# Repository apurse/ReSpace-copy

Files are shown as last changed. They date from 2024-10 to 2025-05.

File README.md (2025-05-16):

# RE-SPACE_GAM390

## How to start app:

### Normal start:

Open the terminal and enter: 
```
cd Re-Space-App; npm install; npx expo start -c
```

### Direct connection:
If normal start doesn't work.
Open the terminal and enter: 
```
cd Re-Space-App; npm install; npx expo start --tunnel -c
```

### Fix dependencies after update:
```
npm config set legacy-peer-deps true
```

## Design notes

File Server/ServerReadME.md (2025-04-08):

## Setup:

### Server setup: hub_communication.py

cd Server; pip install socket asyncio websockets json serial; python hub_communication.py

### Simulating a robot: robot-testing.py

cd Server; cd testing; python robot-testing.py

### wsServer.py

pip install socket asyncio websockets json serial; python wsServer.py

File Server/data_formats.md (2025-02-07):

App -> Hub:\
Control movements\
	`{type: "control", target: "<UUID>", direction: "<text_direction>"}`\
Current furniture layout (manually set)\
	`{type: "current_layout", locations: "{{id: <int>, x: <int>, y: <int>}, {id: <int>, x: <int>, y: <int>}}"}`\
Desired Layout information\
	Furniture ID's with x/y coords\
	`{type: "desired_layout", locations: "{{id: <int>, x: <int>, y: <int>}, {id: <int>, x: <int>, y: <int>}}"}`\
Status control\
	Turn robots on/off\
	`{type: "power", target: "<UUID>", data: "<on/off>"}`

*(Possible: Send furniture types/sizes to be stored on hub)*

Hub -> App:\
Real current layout configuration\
	`{type: "current_layout", locations: "{{id: <int>, x: <int>, y: <int>}, {id: <int>, x: <int>, y: <int>}}"}`\
Robot Status\
	`{type: "status", robot_id: <Websocket UUID>, battery: <int>, location: {x: <int>, y: <int>}, current_activity: "<task_id>"}`\

Robot -> Hub:\
	Robot status\
    `{type: status, battery: <int>, location: {x: <int>, y: <int>}, current_activity: "<task_id>"}`\
	Current location of a furniture item\
		*(Either from just being dropped off, or scanned with ArUco marker)*\
		`{type: "furniture_location", id: <int>, location: {x: <int>, y: <int>}}`

Hub -> Robot:\
	Go-to x/y\
`{type: "move", location: {x: <int>, y: <int>}`\
	Send move task\
`{"type": "move_task", "location_from": {"x": <fromX>, "y": <fromY>}, "location_to": {"x": <toX>, "y": <toY>}}`

Hub -> Swarm script:\
	Current robot ID's / Status'\
	Desired Configuration layout\
	Current furniture positions

Swarm script -> Hub:\
	Send move task\

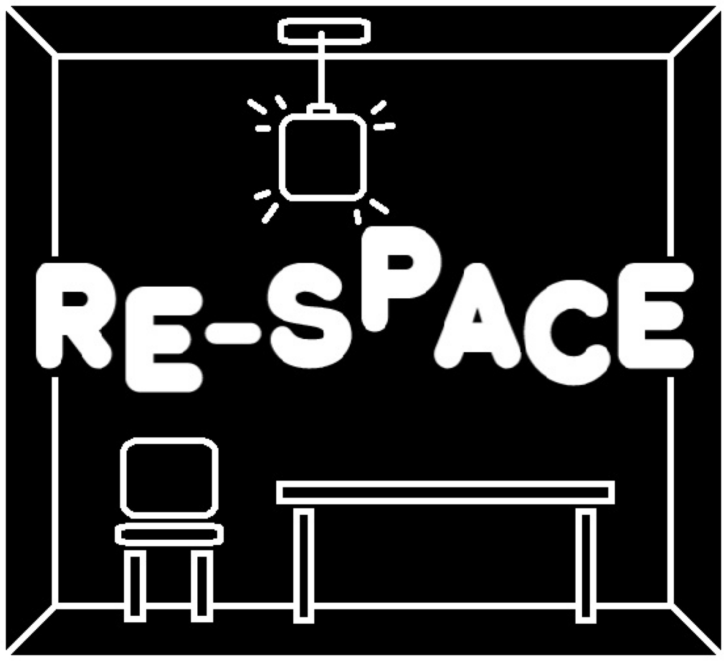
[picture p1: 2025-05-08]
Re-Space-App/assets/images/inverted.png

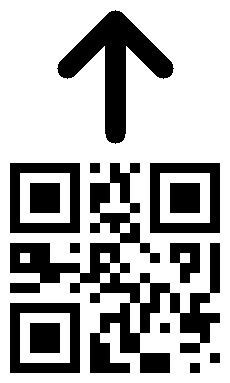
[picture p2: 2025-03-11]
Server/combined.png

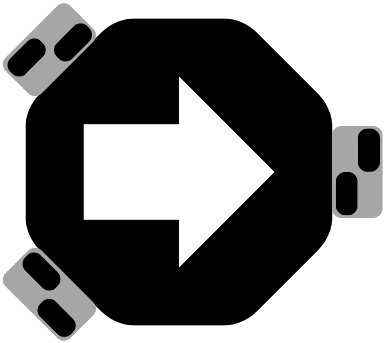
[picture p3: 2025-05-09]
Server/robot.png

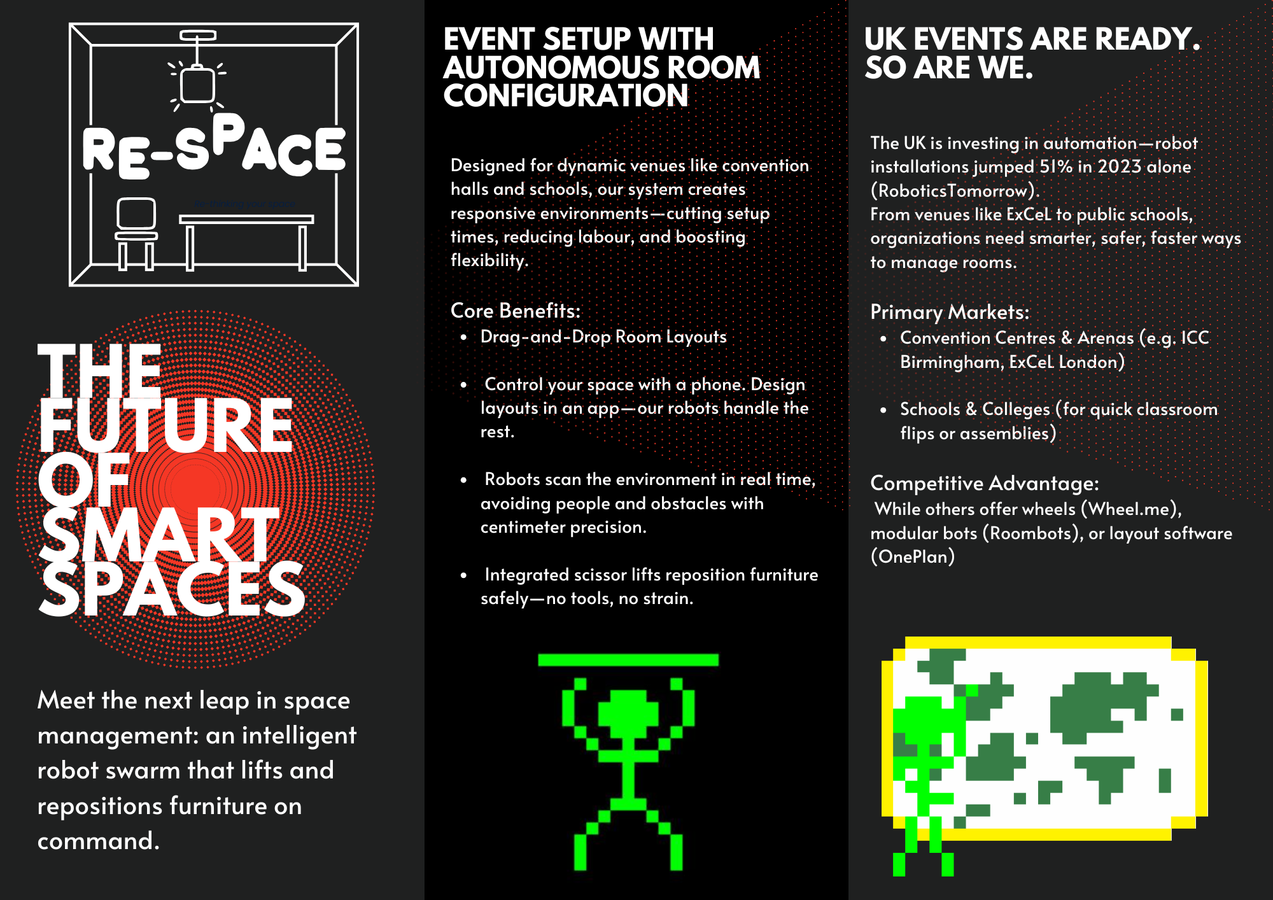
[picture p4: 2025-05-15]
Documentation/BrochurePG1.png

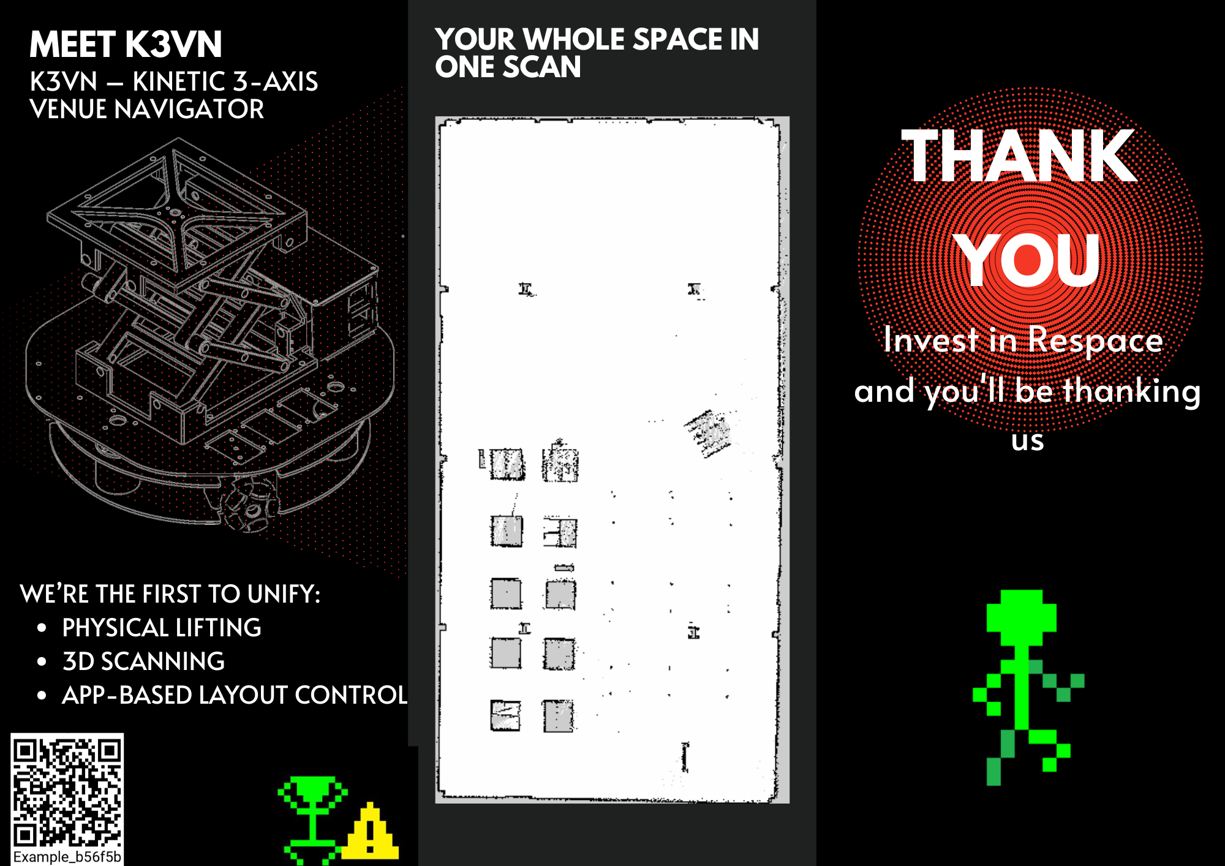
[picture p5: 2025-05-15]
Documentation/BrochurePG2.png

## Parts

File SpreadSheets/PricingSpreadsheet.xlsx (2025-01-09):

Component | price | amount | Cost
Pi4 | £55 | 2 | 110
Pi Pico | £3.90 | 1 | 3.9
Stepper motor | £9.5 | 1 | 10
stepper motor driver | £1.50 | 1 | 1.5
Filament(1 reel) | £20 | 500 grams | 20
Motors | £5 | 3 | 15
Omni Wheels | £5 | 3 | 15
Acrylic600mmx300mm | £10 | 1 | 10
PS3 eyetoy | £5 | 1 | 5
coupling | £2 | 3 | 6
Custom PCB | £30 | 1 | 30
LiPo battery | £32 | 1 | 32
 |  |  | 258.4

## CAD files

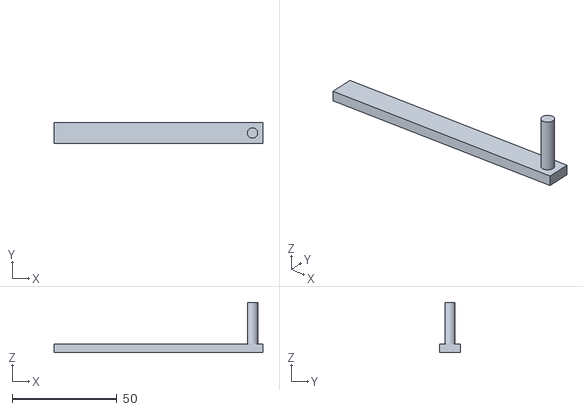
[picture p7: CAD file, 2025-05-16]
CAD/Future Developments/Fork Lift Prototyping/slider legs in face cam v1.stl
100.0 x 10.0 x 24.0

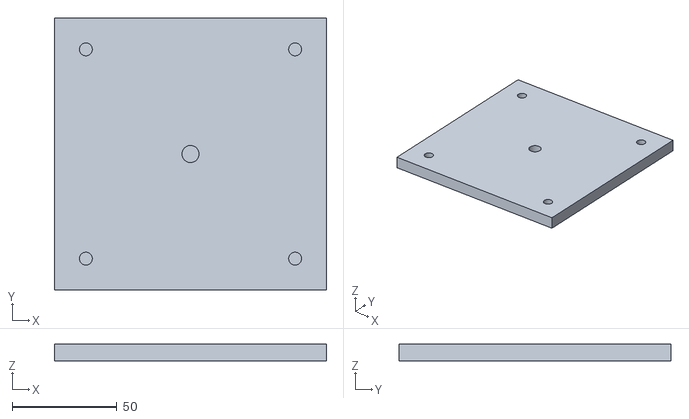
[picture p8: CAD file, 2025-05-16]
CAD/Future Developments/Fork Lift Prototyping/top plate mk2 v1.stl
130.0 x 130.0 x 8.00

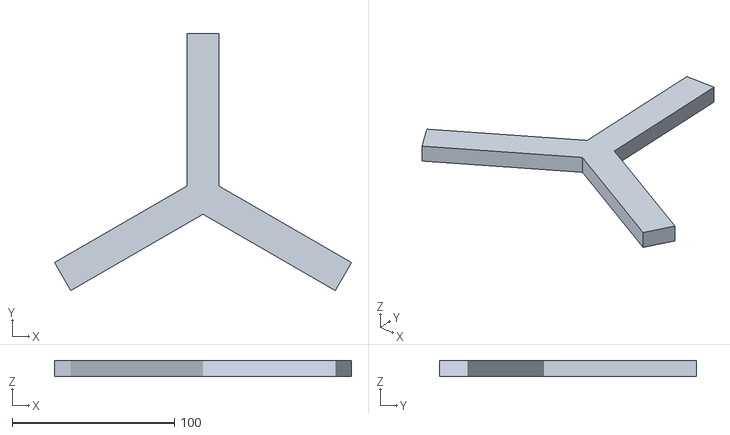
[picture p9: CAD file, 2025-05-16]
CAD/Future Developments/Fork Lift Prototyping/bottom of face cam v1.stl
183.2 x 158.7 x 10.0

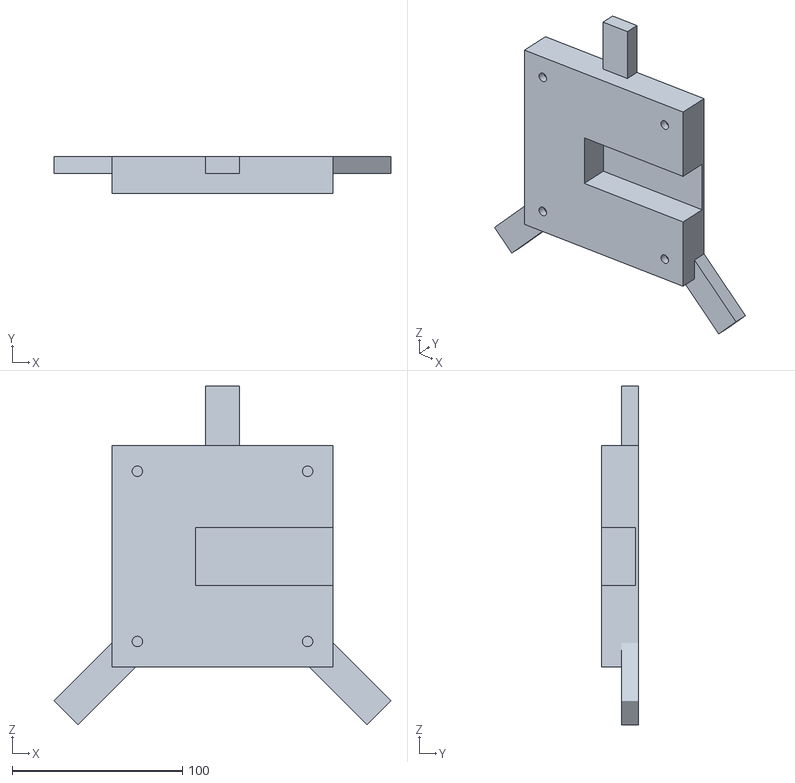
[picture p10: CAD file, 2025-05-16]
CAD/Future Developments/Fork Lift Prototyping/base mk2 v2.stl
198.0 x 22.0 x 199.0

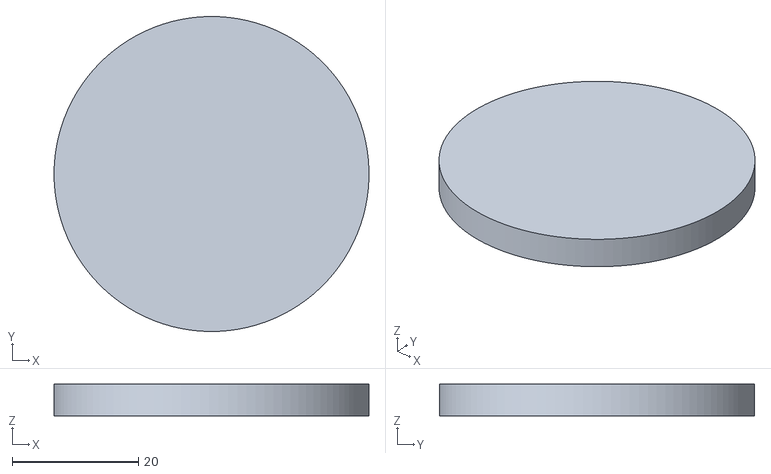
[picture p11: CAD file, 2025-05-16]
CAD/Future Developments/Fork Lift Prototyping/face of face cam v1.stl
50.0 x 50.0 x 5.00

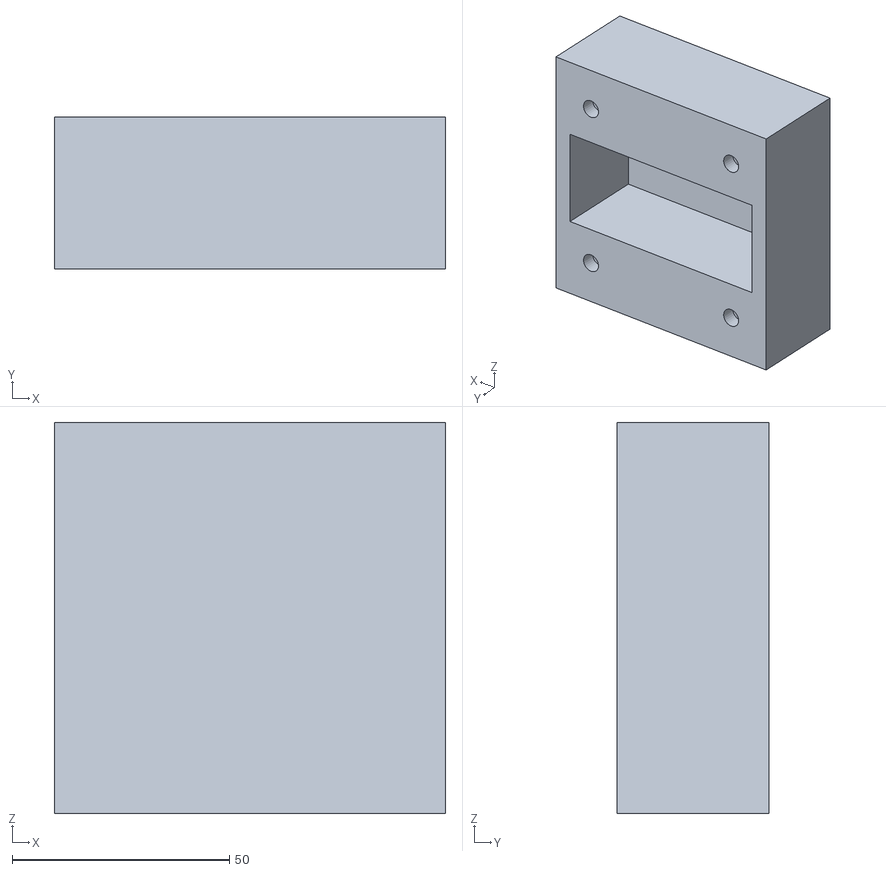
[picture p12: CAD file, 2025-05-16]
CAD/Future Developments/Fork Lift Prototyping/base v4.stl
90.0 x 35.0 x 90.0

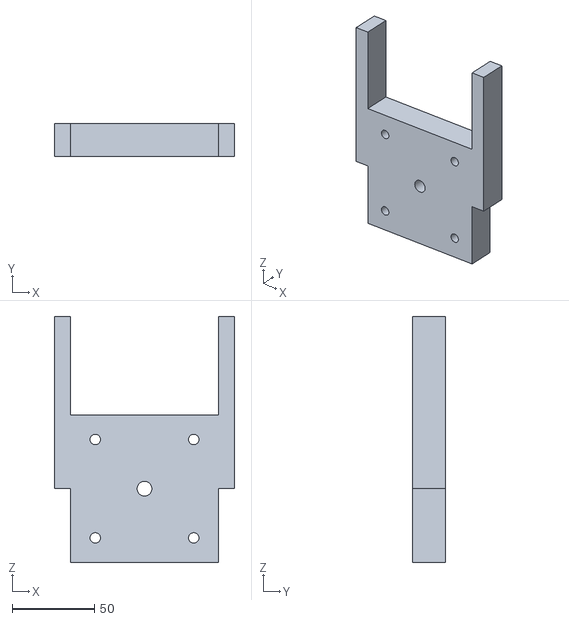
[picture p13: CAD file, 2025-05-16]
CAD/Future Developments/Fork Lift Prototyping/lifting part v3.stl
110.0 x 20.0 x 150.0

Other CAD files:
CAD/Base/Alternate Motor Mount v1.f3d
CAD/Base/Bottom Plate v9.f3d
CAD/Base/Full Assembly v51.f3z
CAD/Base/Lower Post v7.f3d
CAD/Base/Middle Plate v11.f3d
CAD/Base/Middle Post v3.f3d
CAD/Base/Top Plate v26.f3z
CAD/Base/holder v2.f3d
CAD/Dock/Assembly/FullDock.f3z
CAD/Dock/componets/LeftSlot v6.f3d
CAD/Dock/componets/MultiSideSlot v5.f3d
CAD/Dock/componets/RightSlot v4.f3d
CAD/Dock/componets/TOPpanel v1.f3d
CAD/Dock/componets/side panel v6.f3d
CAD/Peripherals/LED bumper v7.f3d
CAD/Scissor Lift/Scissor Assembly v22.f3z
CAD/Scissor Lift/new base plate v11.f3z
CAD/Scissor Lift/new inner arm v1.f3d
CAD/Scissor Lift/new outer arm v4.f3d
CAD/Scissor Lift/new top of lift v2.f3z
CAD/Scissor Lift/slider v24.f3z
CAD/Scissor Lift/small slider v1.f3d

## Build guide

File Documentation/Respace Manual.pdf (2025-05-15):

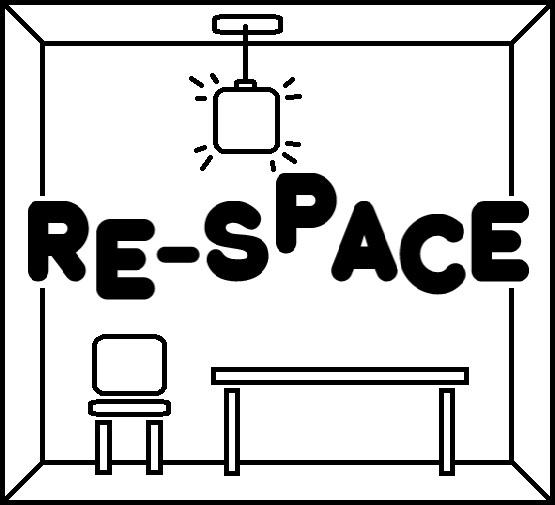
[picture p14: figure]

# ReSpace Manual

# Operating a K3VN Unit with the Proprietary App

K3VN – Kinetic 3-Axis Venue Navigator

## Robot Setup Guide

Once your robot has been delivered, there are two main steps you need to complete before using it:

1. Set up the Hub
- Choose an appropriate space for the Hub.
- Plug it into a mains power outlet.
2. Power on the Robot
- Locate the E-Stop button on the robot.
- Twist the button to turn the robot on.
- Push the button to turn the robot off.

## Configuring the App

Logging In

Once you've installed the app, you’ll be prompted to log in.

- Enter your username and password.
- If this is your first time, tap Create Account.

- If you already have an account, tap Log In.

Room Scanning

1. Tap the Rooms tab at the bottom of the screen.

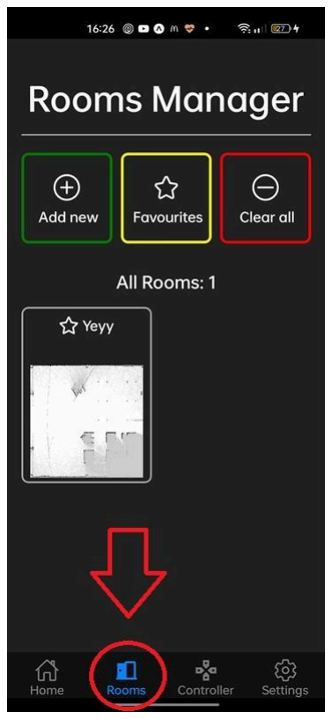
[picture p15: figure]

2. Tap Add New Room.
3. Enter a name for the room and tap Create. (You will be taken to the Room Details screen.)
4. Tap the Scanning option on the details page.

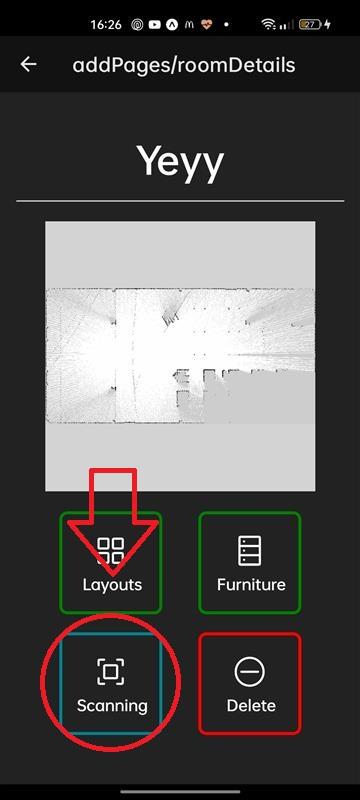
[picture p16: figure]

5. Tap the dropdown and select the desired robot.

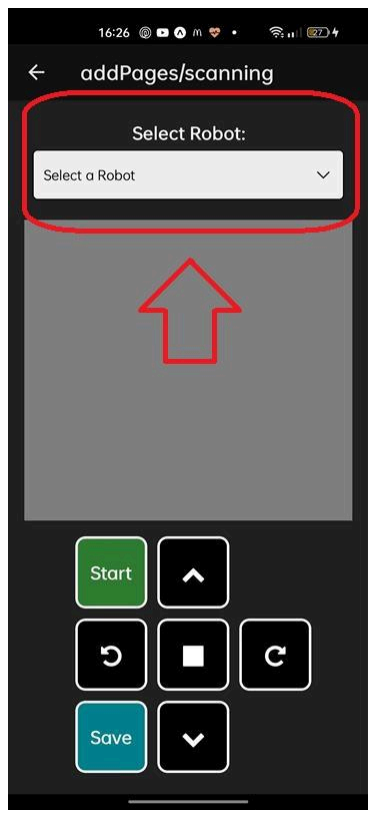
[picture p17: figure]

6. Tap Start.
- A live feed from the robot will appear.
- Use the four arrow keys (cardinal directions) to manually control the robot.

7. Move the robot around the room until you are satisfied with the scan.
8. Once all sides of the room are scanned, tap Save.

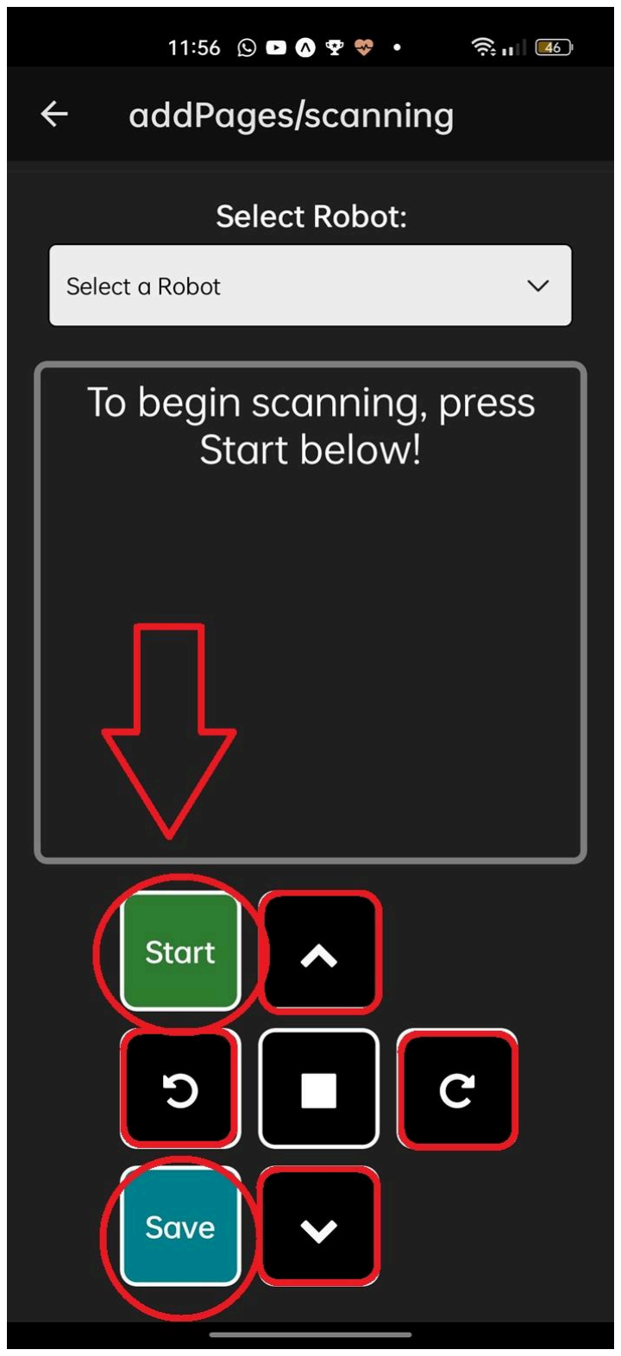
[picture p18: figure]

Adding Furniture

1. Swipe back once you’ve saved the scan.
2. Tap the Add Furniture button.
3. Enter the furniture’s dimensions as prompted.
4. Tap Save Furniture.

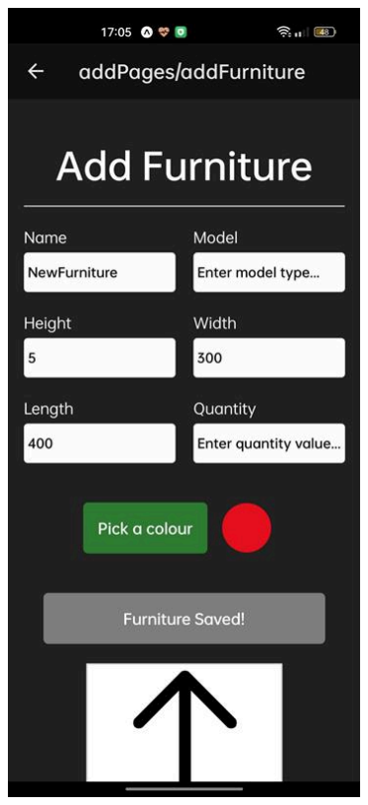
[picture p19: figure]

5. A QR code will appear—tap the Download button to save it to your camera roll.
6. Print the QR code and stick it to the underside of the furniture so it’s clearly visible (preferably in a large size).

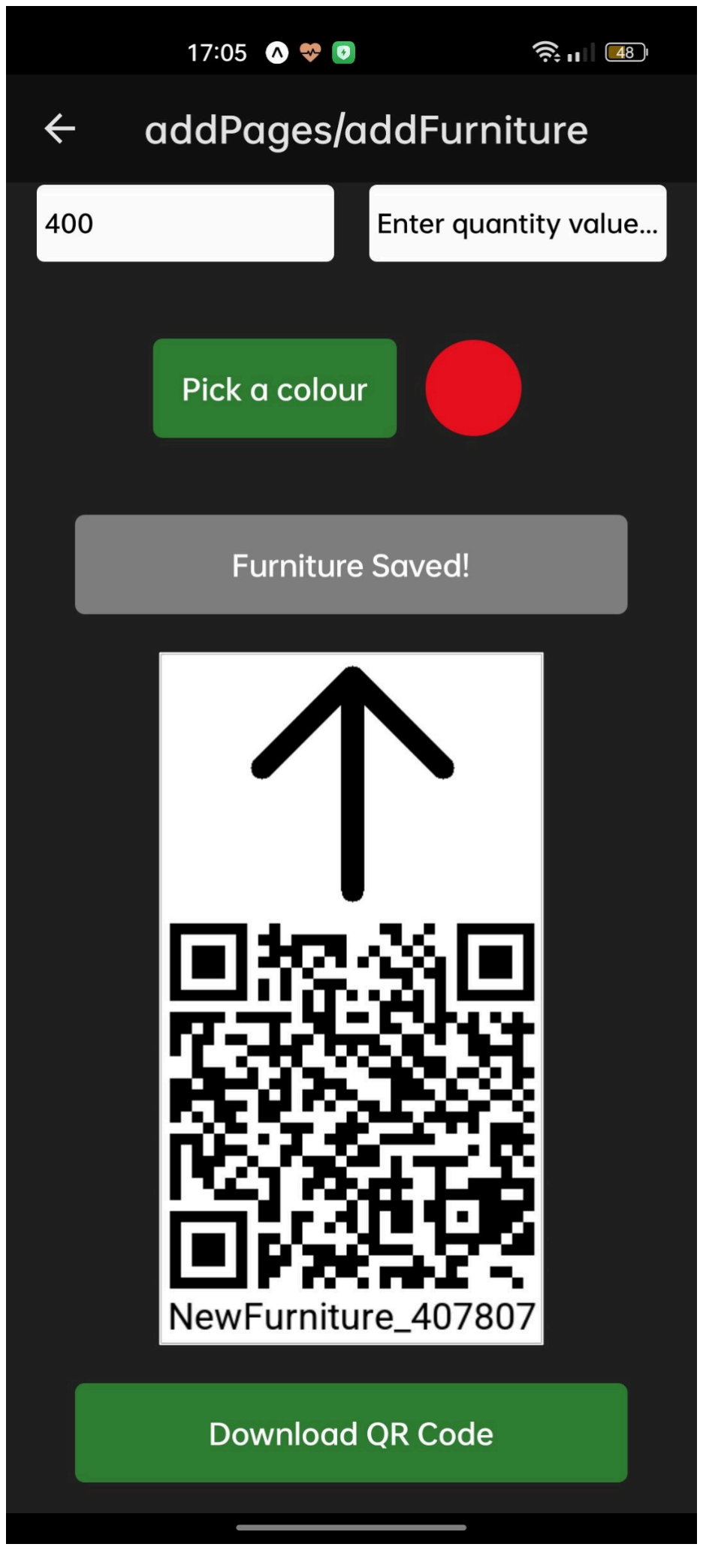
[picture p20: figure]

Adding New Layouts

1. Once a room scan and furniture are saved, go to the Room Details page.
- The most recent scan will appear.
2. Tap the Layouts tab at the bottom of the Room Details page.

3. Layout manager -> add new layout
4. Add a title for the layout.

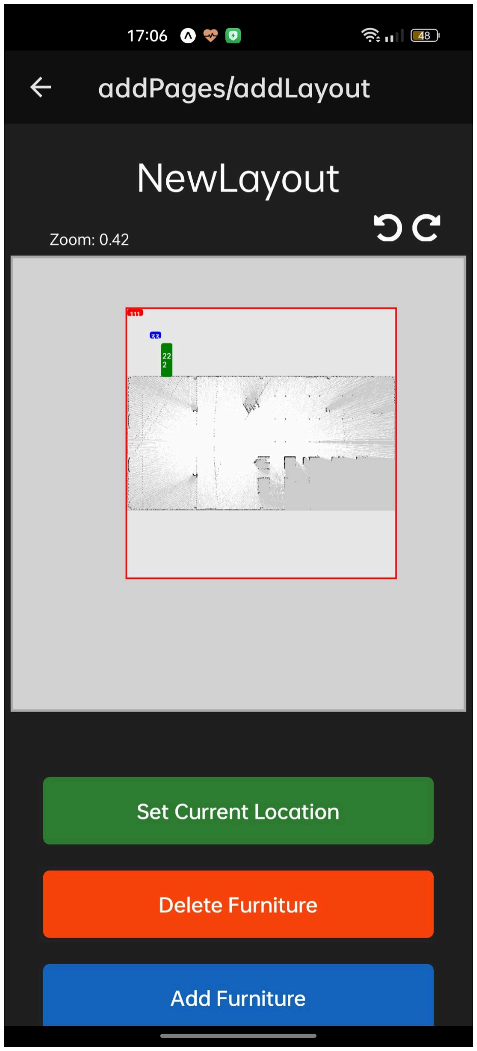
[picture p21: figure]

5. Tap the Add Furniture button.
6. Select the desired piece of furniture.
7. Drag the furniture to its current location.
8. Once you’ve placed all the furniture you want:
- Tap Set Current Location.
9. You’ll now be prompted to drag the furniture again—this time to the desired location.
10. Drag the furniture.
11. Tap Save Layout.

## System Running Page

- After saving the layout, tap Ready to Go.

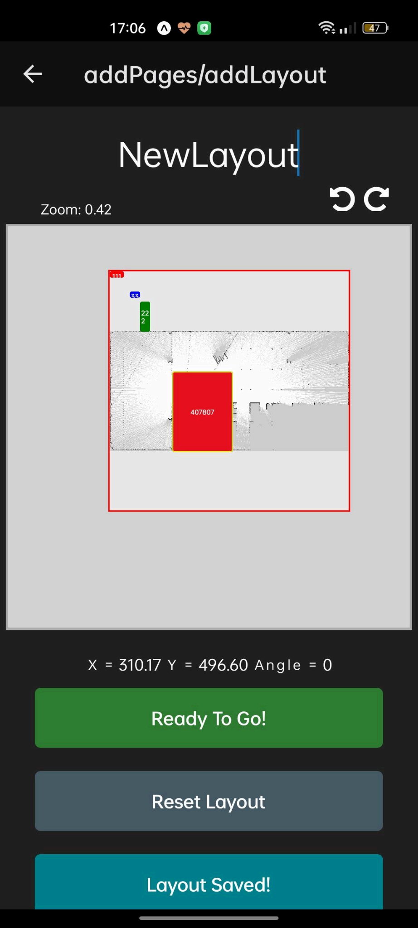
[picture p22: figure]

- The robot’s current location will load, along with a progress bar.
- The picked up furniture will update with the robots current position.
- If anything unusual happens, press the Emergency Stop button.
- Once the progress bar is full, the robot will have completed the move task.

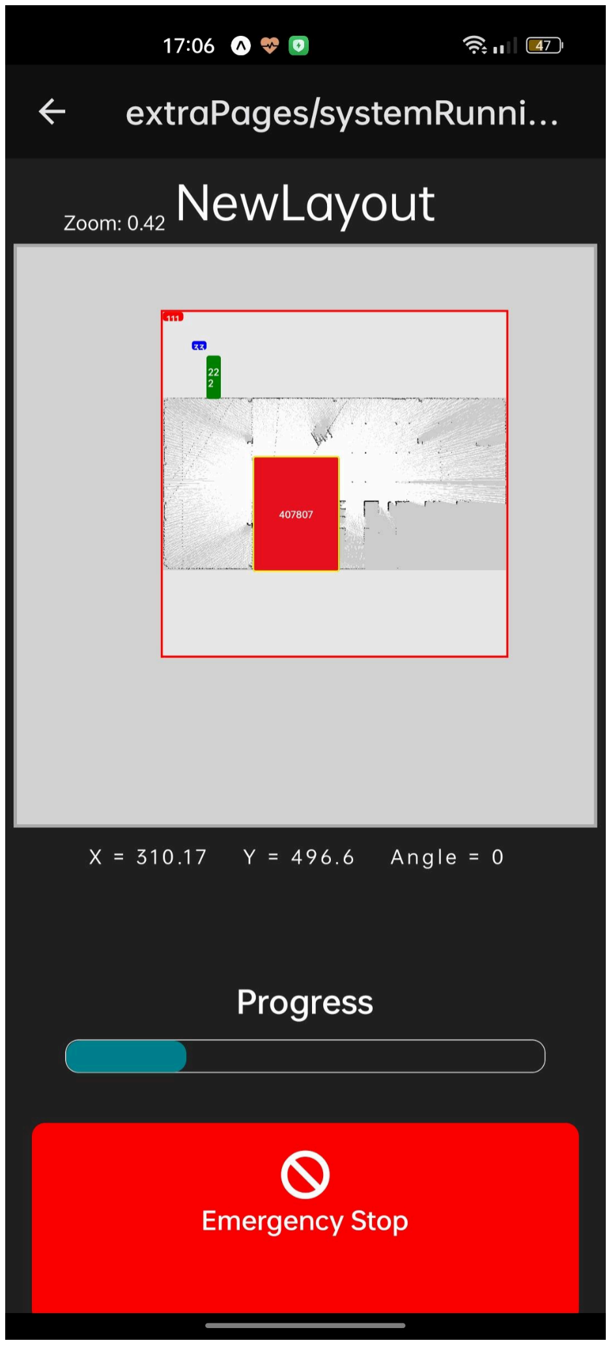
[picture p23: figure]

- Return to the home screen to add more rooms, furniture, or layouts.

## Account Settings

1. Go to the Settings tab at the bottom of the screen.
2. Tap Account Settings.
3. Re-enter your credentials as desired.

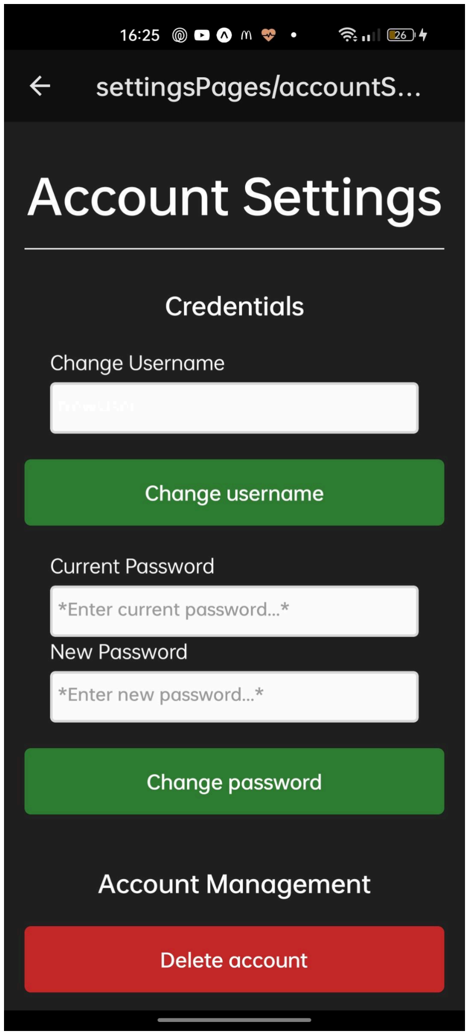
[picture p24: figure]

## General Settings

- In Settings, you can enable Dark Mode.
- You can also test the connection to ensure your robots are properly connected.

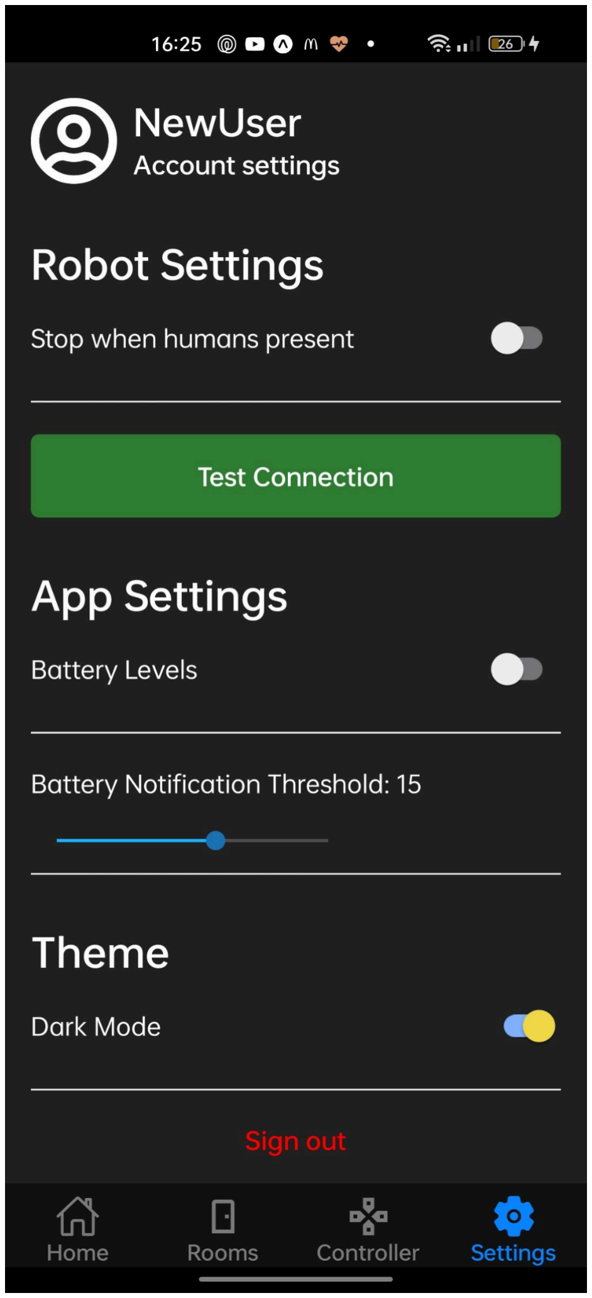
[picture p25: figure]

## Main Screen

- View the robot’s current battery life.
- See a list of connected robots.

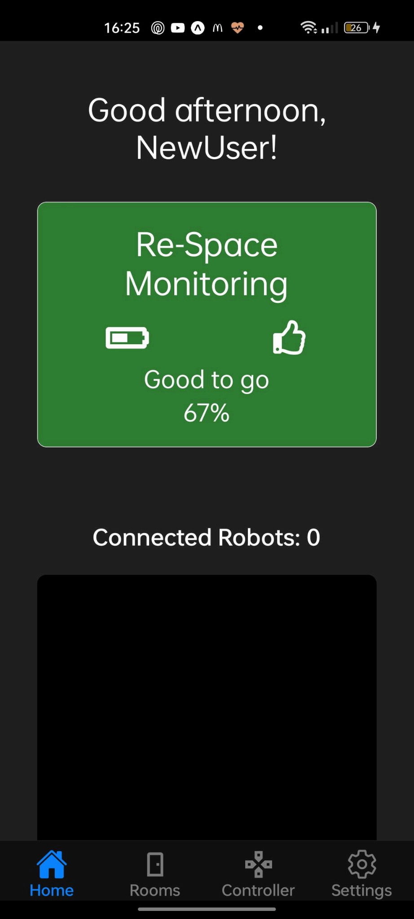
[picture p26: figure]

## Manual Control

1. Tap the Controller tab.
2. Use the arrow keys to manually control the robot.

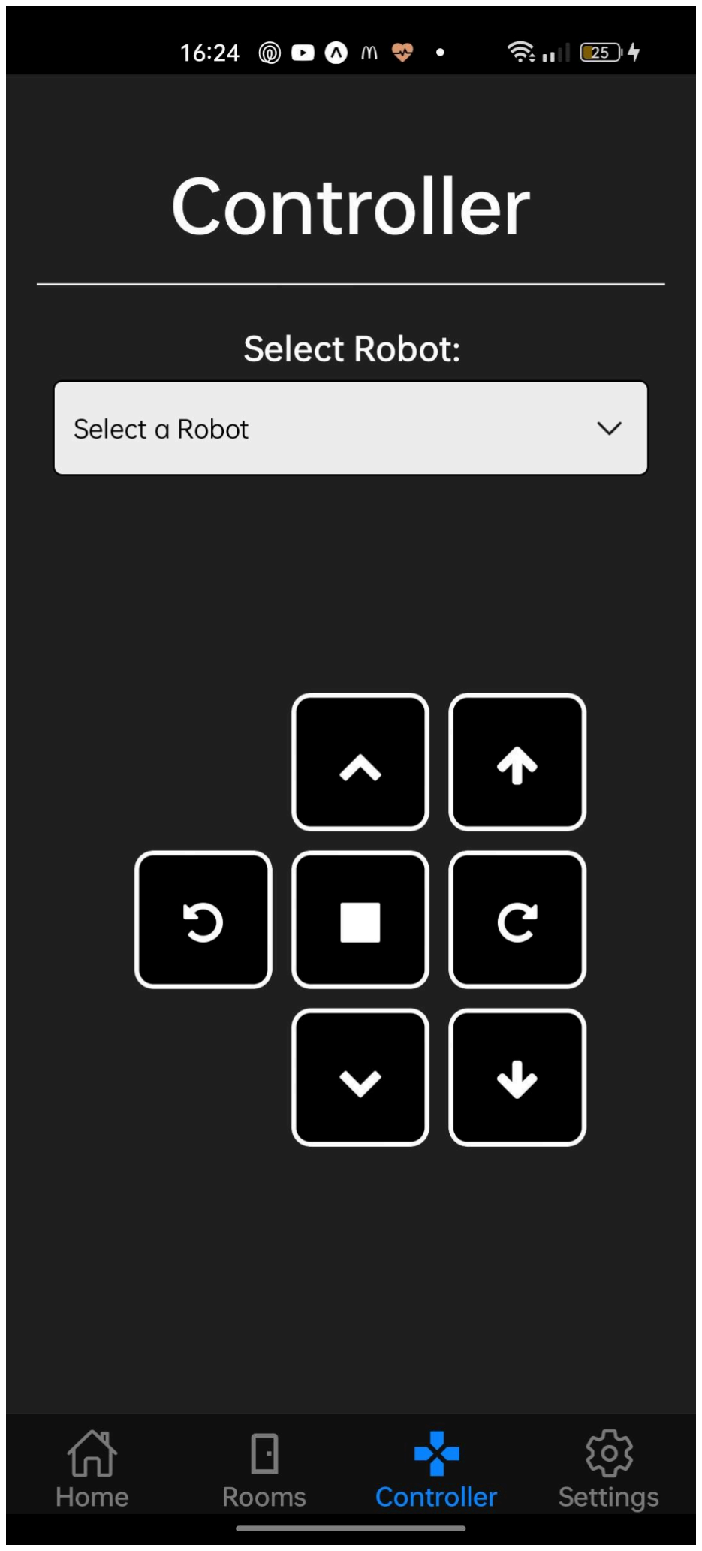
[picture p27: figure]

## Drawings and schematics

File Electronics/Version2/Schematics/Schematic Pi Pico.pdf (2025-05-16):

## ENDSTOP MICROSWITCH CONNECTORS

## BATTERY PROBE

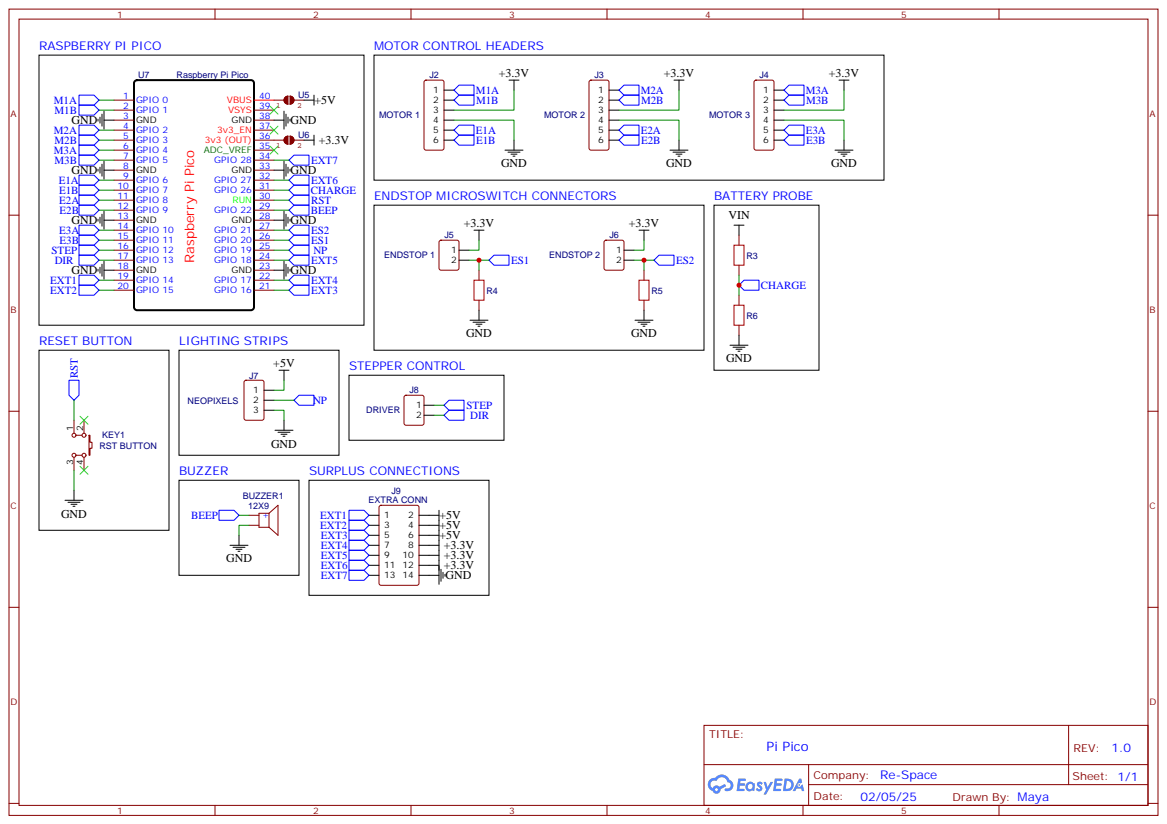
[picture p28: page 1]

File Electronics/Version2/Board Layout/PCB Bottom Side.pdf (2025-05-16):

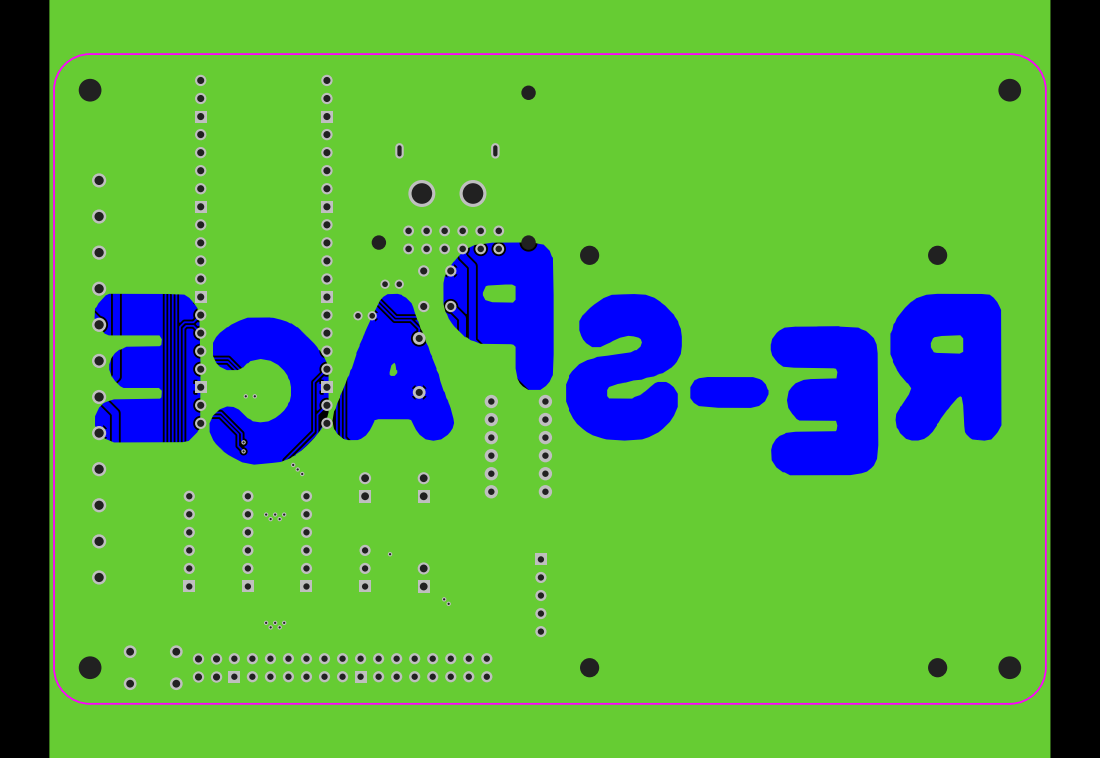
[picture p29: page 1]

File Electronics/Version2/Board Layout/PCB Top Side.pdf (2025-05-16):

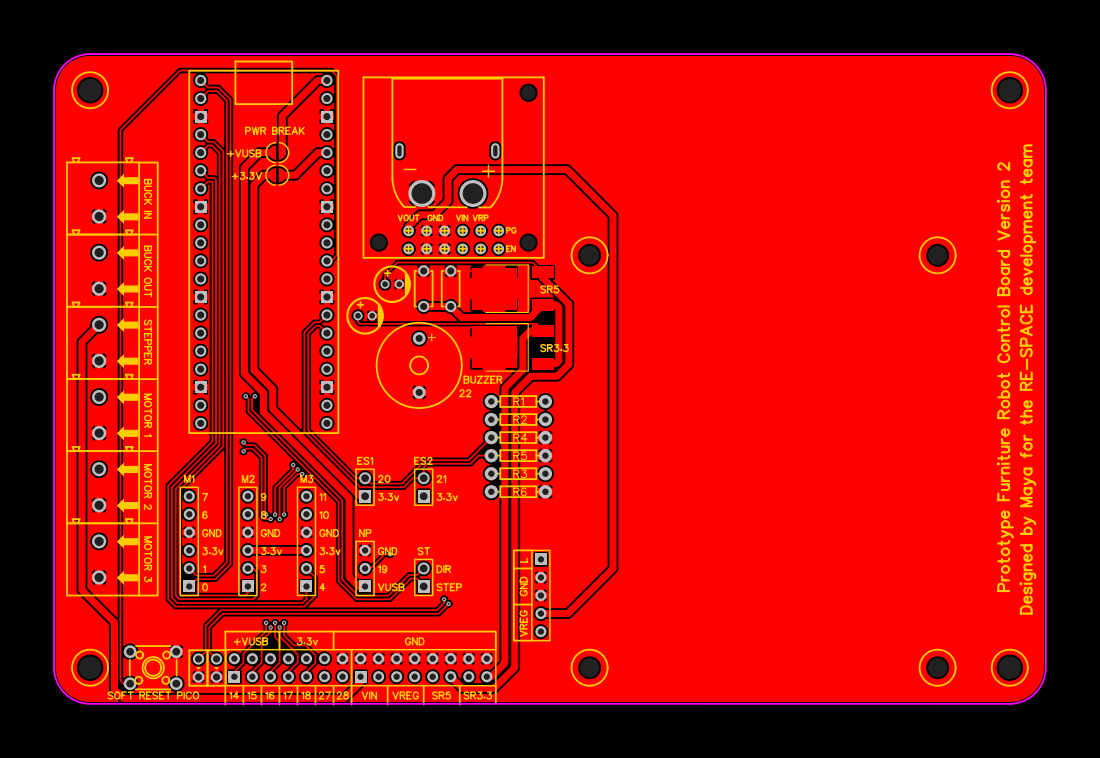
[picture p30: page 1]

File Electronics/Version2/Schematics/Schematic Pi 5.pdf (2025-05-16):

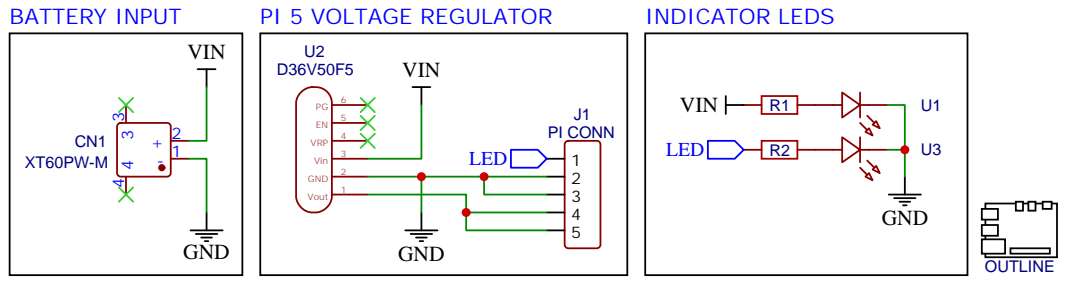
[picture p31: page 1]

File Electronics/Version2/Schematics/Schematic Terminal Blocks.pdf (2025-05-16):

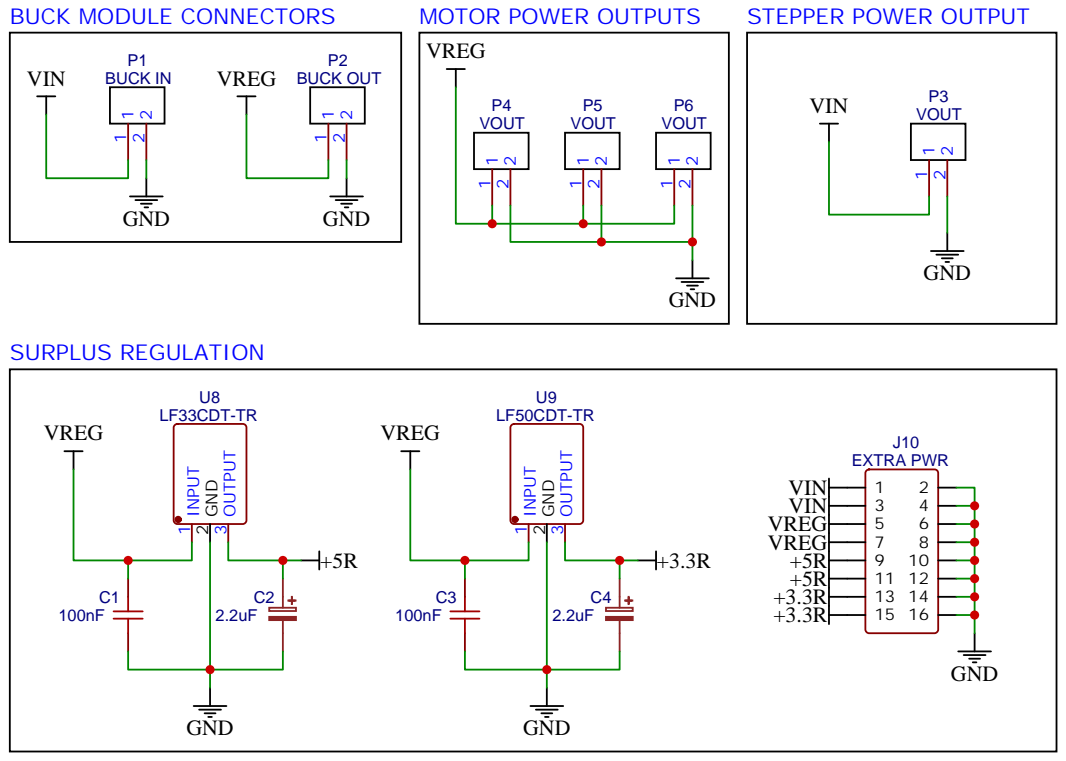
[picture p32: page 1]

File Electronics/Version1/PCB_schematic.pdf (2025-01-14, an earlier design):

## GND

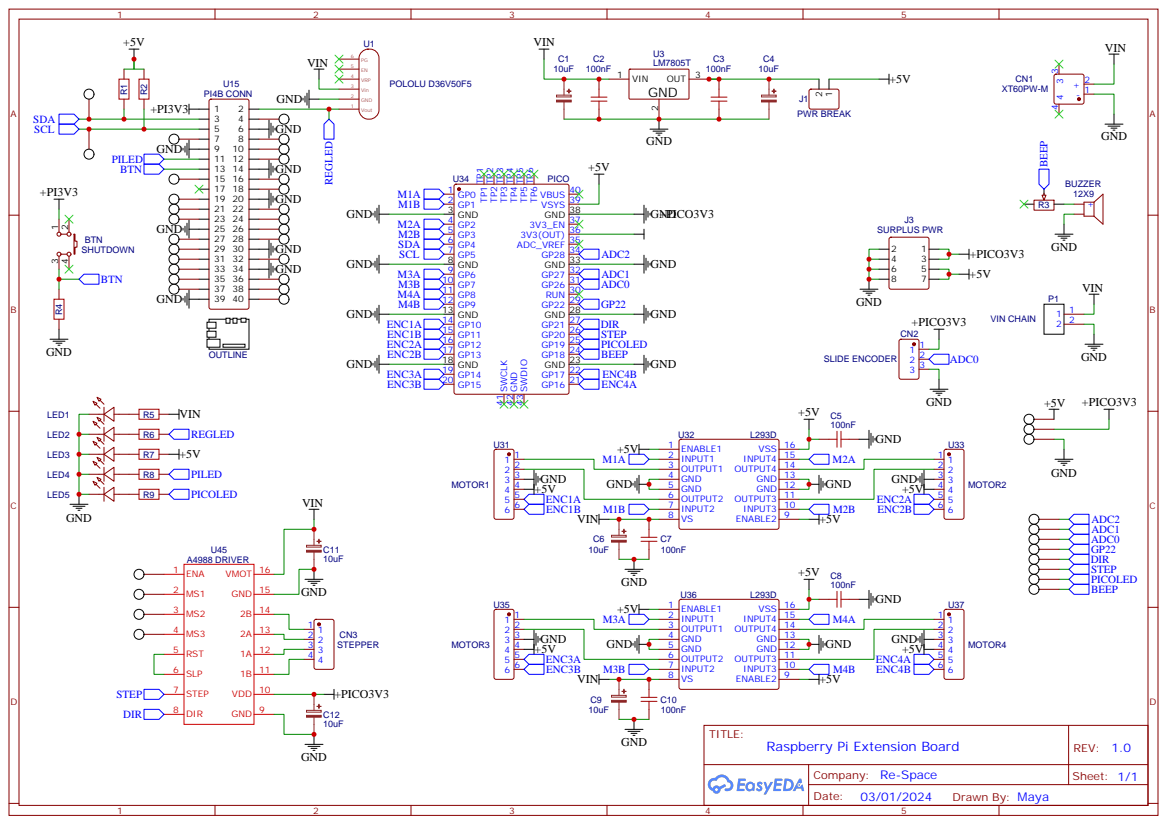
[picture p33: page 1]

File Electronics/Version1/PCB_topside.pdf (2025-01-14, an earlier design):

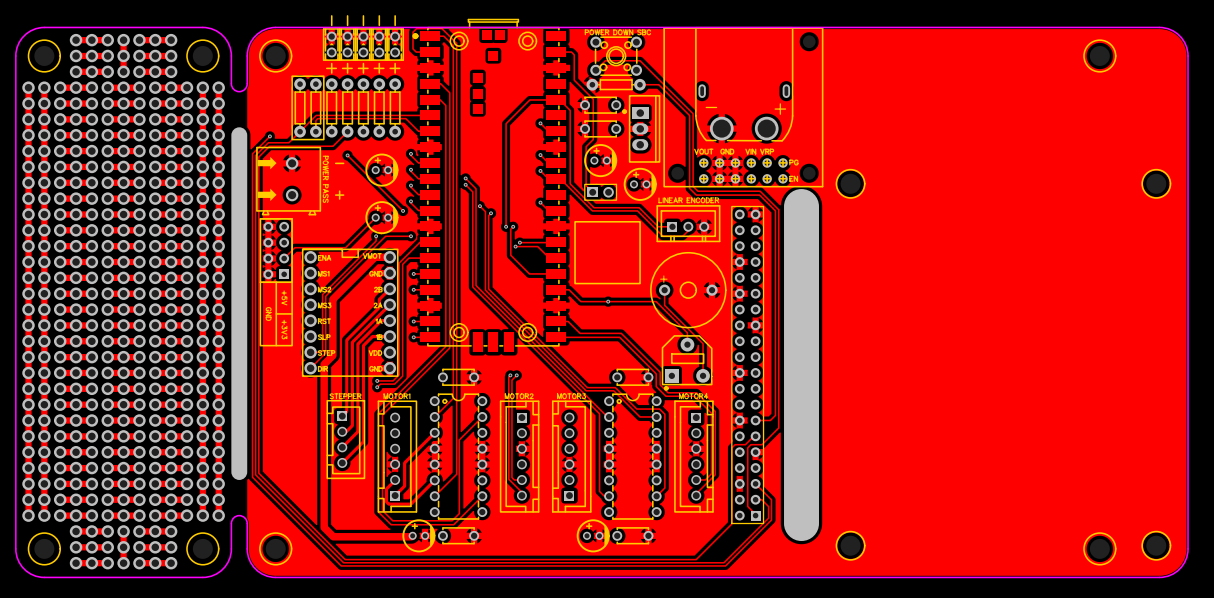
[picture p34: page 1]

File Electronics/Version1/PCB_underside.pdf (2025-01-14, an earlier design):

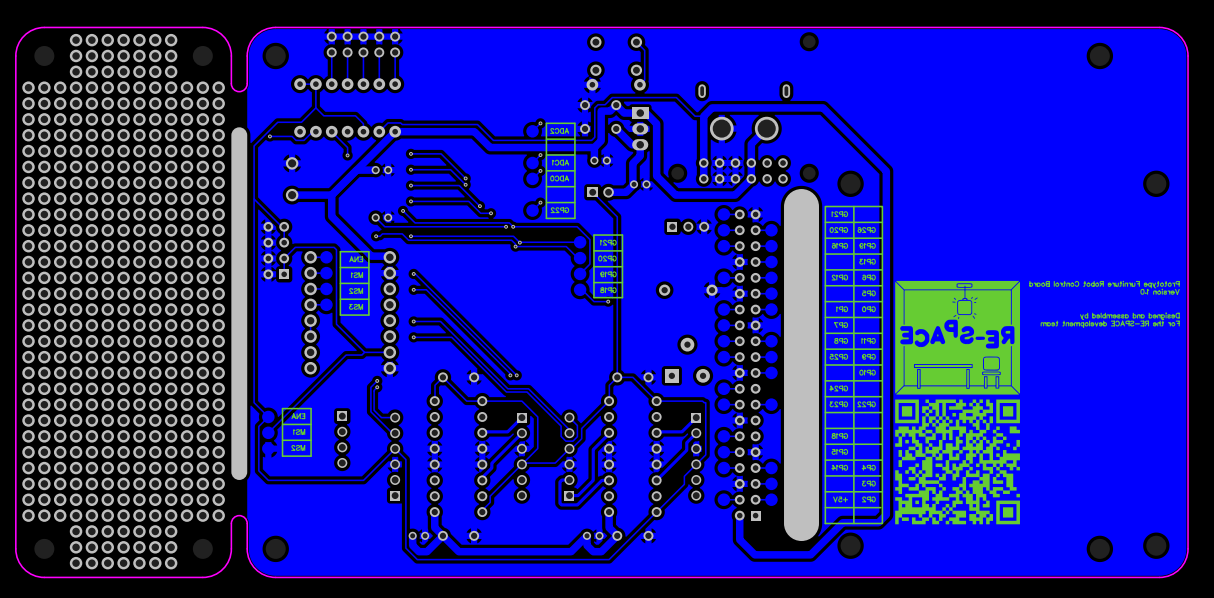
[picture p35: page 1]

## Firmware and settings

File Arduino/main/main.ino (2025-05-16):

#include "pio_encoder.h"
#include "pico/multicore.h"
#include "hardware/timer.h"
#include <AccelStepper.h>
#include <FastLED.h>

#define NUMPIXELS_PER_STRIP 28
#define NUM_STRIPS 3

#define LED_PIN_1 14
#define LED_PIN_2 15
#define LED_PIN_3 16

CRGB strip1[NUMPIXELS_PER_STRIP];
CRGB strip2[NUMPIXELS_PER_STRIP];
CRGB strip3[NUMPIXELS_PER_STRIP];

#define stepPin 12
#define dirPin 13
#define limitSwitchPin 21
#define motorInterfaceType 1

AccelStepper stepper(motorInterfaceType, stepPin, dirPin);

int switchState;
int ms = 16;
const float r = 0.029;  // Wheel radius (m)
const float circ = 3.14 * 2 * r;  // Wheel circum (m)
const float d = 0.155;   // Distance from wheel center to robot center (m)
const float dt = 0.1;  // Time step (s)
String transmission;

// Initial position of robot
float x = 0.0, y = 0.0, theta = 0.0, vx = 0.0, vy = 0.0, omega = 0.0;

// Initial HZ of motors
float HZ1 = 0.0, HZ2 = 0.0, HZ3 = 0.0;

// Motor class with encoder
class Motor {
  private:
    int motorPin1, motorPin2;
    PioEncoder encoder;
    int previousEncoder;
    float Kp, Ki, Kd;
    float previousError, integral;
    float targetSpeed, currentSpeed;
    float previousTime;
    float ticks_per_rev = 2480;

  public:
    Motor(int m1, int m2, int e1, float kp, float ki, float kd)
      : motorPin1(m1), motorPin2(m2), encoder(e1), Kp(kp), Ki(ki), Kd(kd), previousError(0), integral(0), targetSpeed(0) {}

    void begin() {
      pinMode(motorPin1, OUTPUT);
      pinMode(motorPin2, OUTPUT);
      encoder.begin();
      previousTime = millis();
      currentSpeed = 0.0;
      previousEncoder = 0;
    }

    void setTargetSpeed(float speed) {
      targetSpeed = speed;
    }

    void setPower(float power) {
      int pwmPower = constrain(abs(power) * 255, 0, 255);
      if (power >= 0) {
        analogWrite(motorPin1, pwmPower);
        analogWrite(motorPin2, 0);
      } else {
        analogWrite(motorPin1, 0);
        analogWrite(motorPin2, pwmPower);
      }
    }

    void pidControl() {
      unsigned long timeNow = micros();                              // Use micros() for more precise timing
      float deltaTime = (timeNow - this->previousTime) / 1000000.0;  // Convert microseconds to seconds
      long currentEncoder = getEncoderCount();

      // Calculate speed in counts per second (or other suitable units)
      this->currentSpeed = (currentEncoder - this->previousEncoder) / (deltaTime * this->ticks_per_rev);

      float error = this->targetSpeed - this->currentSpeed;
      integral += error * deltaTime;
      float derivative = (error - this->previousError) / deltaTime;
      float output = Kp * error + Ki * integral + Kd * derivative;
      integral = integral * 0.99; // leaky eeky integral
      setPower(output);

      this->previousError = error;
      this->previousTime = timeNow;
      this->previousEncoder = currentEncoder;
    }

    long getEncoderCount() {
      return encoder.getCount();
    }
    float getSpeed() {
      return this->currentSpeed;
    }
    float getSetpoint() {
      return this->targetSpeed;
    }
};

//////////////////LIGHTS////////////
void greenChase() {
  const int delayTime = 30;       // Delay between steps
  const int cycles = 10;          // Number of complete cycles
  const int trailLength = 9;      // Number of trailing green pixels

  int totalPixels = NUMPIXELS_PER_STRIP * NUM_STRIPS;

  while (true) {
    for (int c = 0; c < cycles; c++) {
      for (int head = 0; head < totalPixels; head++) {
        // Clear all strips
        fill_solid(strip1, NUMPIXELS_PER_STRIP, CRGB::Black);
        fill_solid(strip2, NUMPIXELS_PER_STRIP, CRGB::Black);
        fill_solid(strip3, NUMPIXELS_PER_STRIP, CRGB::Black);

        for (int t = 0; t < trailLength; t++) {
          int pos = (head - t + totalPixels) % totalPixels;
          int strip = pos / NUMPIXELS_PER_STRIP;
          int index = pos % NUMPIXELS_PER_STRIP;

          if (strip == 0) strip1[index] = CRGB::Green;
          else if (strip == 1) strip2[index] = CRGB::Green;
          else if (strip == 2) strip3[index] = CRGB::Green;
        }

        FastLED.show();
        sleep_ms(delayTime);
      }
    }
  }
}

void redYellowChase() {
  const int delayTime = 50;
  const int cycles = 10;
  const int totalPixels = NUMPIXELS_PER_STRIP * NUM_STRIPS;

  while (true) {
    for (int offset = 0; offset < NUMPIXELS_PER_STRIP + cycles; offset++) {
      for (int i = 0; i < NUMPIXELS_PER_STRIP; i++) {
        CRGB color = ((i + offset) % 2 == 0) ? CRGB::Red : CRGB::Yellow;
        strip1[i] = color;
        strip2[i] = color;
        strip3[i] = color;
      }

      FastLED.show();
      sleep_ms(delayTime);
    }
  }
}


void pulsatingGreen() {
  const int delayTime = 10;
  const int cycles = 3;

  while (true) {
    for (int c = 0; c < cycles; c++) {
      // Fade in
      for (int brightness = 0; brightness <= 255; brightness++) {
        fill_solid(strip1, NUMPIXELS_PER_STRIP, CRGB(0, brightness, 0));
        fill_solid(strip2, NUMPIXELS_PER_STRIP, CRGB(0, brightness, 0));
        fill_solid(strip3, NUMPIXELS_PER_STRIP, CRGB(0, brightness, 0));
        FastLED.show();
        sleep_ms(delayTime);
      }

      // Fade out
      for (int brightness = 255; brightness >= 0; brightness--) {
        fill_solid(strip1, NUMPIXELS_PER_STRIP, CRGB(0, brightness, 0));
        fill_solid(strip2, NUMPIXELS_PER_STRIP, CRGB(0, brightness, 0));
        fill_solid(strip3, NUMPIXELS_PER_STRIP, CRGB(0, brightness, 0));
        FastLED.show();
        sleep_ms(delayTime);
      }
    }
  }
}

void blueWhiteChase() {
  const int delayTime = 50;
  const int cycles = 10;

  while (true) {
    for (int offset = 0; offset < cycles; offset++) {
      for (int i = 0; i < NUMPIXELS_PER_STRIP; i++) {
        CRGB color = ((i + offset) % 2 == 0) ? CRGB::Blue : CRGB::White;
        strip1[i] = color;
        strip2[i] = color;
        strip3[i] = color;
      }

      FastLED.show();
      sleep_ms(delayTime);
    }
  }
}

void flashAllRed() {
  const int flashes = 3;
  const int delayTime = 300;

  while (true) {
    for (int i = 0; i < flashes; i++) {
      fill_solid(strip1, NUMPIXELS_PER_STRIP, CRGB::Red);
      fill_solid(strip2, NUMPIXELS_PER_STRIP, CRGB::Red);
      fill_solid(strip3, NUMPIXELS_PER_STRIP, CRGB::Red);
      FastLED.show();
      sleep_ms(delayTime);

      fill_solid(strip1, NUMPIXELS_PER_STRIP, CRGB::Black);
      fill_solid(strip2, NUMPIXELS_PER_STRIP, CRGB::Black);
      fill_solid(strip3, NUMPIXELS_PER_STRIP, CRGB::Black);
      FastLED.show();
      sleep_ms(delayTime);
    }
  }
}

// Instantiate motor objects
Motor motorA(0, 1, 6, 1.0, 0.05, 0.00);
Motor motorB(2, 3, 8, 1.0, 0.05, 0.00);
Motor motorC(4, 5, 10, 1.0, 0.05, 0.00);

// Timer callback function
bool repeatingTimerCallback(struct repeating_timer *t) {
  motorA.pidControl();
  motorB.pidControl();
  motorC.pidControl();
  return true;  // Keep repeating
}

bool repeatingOdomTimerCallback(struct repeating_timer *t) {
  // Update odometry
  // Get wheel speeds
  float w1 = motorB.getSpeed() * r;
  float w2 = motorC.getSpeed() * r;
  float w3 = motorA.getSpeed() * r;

  // Transformation matrix based on derived equations
  float F[3][3] = {
    {0, -1.0 / sqrt(3), 1.0 / sqrt(3)},
    {1.0, -0.5, -0.5},
    { -1.0 / (3 * d), -1.0 / (3 * d), -1.0 / (3 * d)}
  };

  // Compute velocity in robot frame
  vx = F[0][0] * w1 + F[0][1] * w2 + F[0][2] * w3;
  vy = F[1][0] * w1 + F[1][1] * w2 + F[1][2] * w3;
  omega = F[2][0] * w1 + F[2][1] * w2 + F[2][2] * w3;

  // Transform velocity to global frame
  x += -(vx * sin(theta) + vy * cos(theta)) * dt-(vx * cos(theta) - vy * sin(theta)) * dt;
  y += -(vx * sin(theta) + vy * cos(theta)) * dt;
  theta += omega * dt;

  return true;  // Keep repeating
}

void calculateHZ(float VX, float VY, float WZ) {

  float w1 = (VY + d * WZ);
  float w2 = ((-sqrt(3) / 2.0) * VX - 0.5 * VY + d * WZ);
  float w3 = ((sqrt(3) / 2.0) * VX - 0.5 * VY + d * WZ);
  Serial.println(-w1);
  Serial.println(-w2);
  Serial.println(-w3);

  HZ1 = w1 / circ;
  HZ2 = w2 / circ;
  HZ3 = w3 / circ;
}

struct repeating_timer motorTimer;
struct repeating_timer odomTimer;

void setup() {
  Serial.begin(115200);
  motorA.begin();
  motorB.begin();
  motorC.begin();

  FastLED.addLeds<NEOPIXEL, LED_PIN_1>(strip1, NUMPIXELS_PER_STRIP);
  FastLED.addLeds<NEOPIXEL, LED_PIN_2>(strip2, NUMPIXELS_PER_STRIP);
  FastLED.addLeds<NEOPIXEL, LED_PIN_3>(strip3, NUMPIXELS_PER_STRIP);

  FastLED.clear();
  FastLED.show();

  pinMode(limitSwitchPin, INPUT_PULLUP);
  stepper.setMaxSpeed(500 * ms);
  stepper.setAcceleration(4000 * ms);
  multicore_launch_core1(greenChase);
  homing();

  // Start hardware timer with 20ms interval
  add_repeating_timer_ms(-20, repeatingTimerCallback, NULL, &motorTimer);

  add_repeating_timer_ms(-50, repeatingOdomTimerCallback, NULL, &odomTimer);
}

void loop() {
  // Print updated position
  Serial.print(x * 2.86, 3);
  Serial.print(",");
  Serial.print(y * 2.86, 3);
  Serial.print(",");
  Serial.print(theta * 3.1, 3);
  Serial.print(",");
  Serial.print(vx, 3);
  Serial.print(",");
  Serial.print(vy, 3);
  Serial.print(",");
  Serial.print(omega, 3);
  Serial.println();
  delay(50);

  if (Serial.available() > 0) {
    // Read until doesn't wait a specific amount of time so doesn't cause delay
    transmission = Serial.readStringUntil('\n');
    if (transmission == "R") {
      // Reset odom when ROS spins up
      x = 0.0;
      y = 0.0;
      theta = 0.0;
      // Reset motor speed
      motorA.setTargetSpeed(0);
      motorB.setTargetSpeed(0);
      motorC.setTargetSpeed(0);
      // re-home scissor lift
      homing();
    } else if (transmission == "S1") {
      // Segment 1: Use Motor B and C
      motorA.setTargetSpeed(0);
      motorB.setTargetSpeed(0.5);
      motorC.setTargetSpeed(-0.5);
    } else if (transmission == "S2") {
      // Segment 2: Use Motor A and C
      motorA.setTargetSpeed(0.5);
      motorB.setTargetSpeed(0);
      motorC.setTargetSpeed(0.5);
    } else if (transmission == "S3") {
      // Segment 3: Use Motor A and B
      motorA.setTargetSpeed(0.5);
      motorB.setTargetSpeed(-0.5);
      motorC.setTargetSpeed(0);
    } else if (transmission == "S4") {
      motorA.setTargetSpeed(0);
      motorB.setTargetSpeed(0);
      motorC.setTargetSpeed(0);
    } else if (transmission == "U") {
      stepper.runToNewPosition(5500 * ms);
    } else if (transmission == "D") {
      stepper.runToNewPosition(650 * ms);
    } else  {
      // Format data
      // Remove brackets
      transmission.remove(0, 1);
      transmission.remove(transmission.length() - 1);

      // Split by commas
      int comma1 = transmission.indexOf(',');
      int comma2 = transmission.indexOf(',', comma1 + 1);

      float val1 = transmission.substring(0, comma1).toFloat();
      float val2 = transmission.substring(comma1 + 1, comma2).toFloat();
      float val3 = transmission.substring(comma2 + 1).toFloat();

      // calculate rpm values for wheels
      // add boundaries for the calculation
      if (val1 <= 3.2 && val1 >= -3.2 &&
          val2 <= 3.2 && val2 >= -3.2 &&
          val3 <= 3.2 && val3 >= -3.2) {
        calculateHZ(val1, val2, val3);
        Serial.println(HZ1);
        Serial.println(HZ2);
        Serial.println(HZ3);
        motorA.setTargetSpeed(HZ3 * 1.7);
        motorB.setTargetSpeed(HZ1 * 1.7);
        motorC.setTargetSpeed(HZ2 * 1.7);
      }
    }
  }
}

///////////////////////////////LIFT//////////////////////

void homing() {
  switchState = digitalRead(limitSwitchPin);
  while (switchState != 1) {
    switchState = digitalRead(limitSwitchPin);
    stepper.moveTo(-100000000);
    stepper.run();
  }
  stepper.setCurrentPosition(0);
  stepper.runToNewPosition(200 * ms);
  stepper.runToNewPosition(0);
  stepper.runToNewPosition(200 * ms);
  stepper.runToNewPosition(0);
}

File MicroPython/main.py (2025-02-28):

from machine import Pin, PWM, Timer
import time

class Motor:
    def __init__(self, pwm_pin_forward, pwm_pin_reverse, encoder_pin_a, encoder_pin_b,
                 ticks_per_rev=620, Kp=160, Ki=90, Kd=0.05, freq=1000, timer_period=10):
        # Initialize encoder pins
        self.encoder_pin_a = Pin(encoder_pin_a, Pin.IN)
        self.encoder_pin_b = Pin(encoder_pin_b, Pin.IN)
        
        # Initialize motor PWM pins
        self.motor_pwm1 = PWM(Pin(pwm_pin_forward))
        self.motor_pwm2 = PWM(Pin(pwm_pin_reverse))
        self.motor_pwm1.freq(freq)
        self.motor_pwm2.freq(freq)
        
        # PID and encoder parameters
        self.ticks_per_rev = ticks_per_rev
        self.Kp = Kp
        self.Ki = Ki
        self.Kd = Kd
        self.target_rpm = 0
        
        self.encoder_count = 0
        self.last_time = time.ticks_ms()
        self.last_error = 0
        self.integral = 0
        self.rpm = 0  # Store the current RPM
        
        # Attach the interrupt handler to encoder pin A.
        self.encoder_pin_a.irq(trigger=Pin.IRQ_RISING, handler=self._encoder_isr)
        
        # Setup a timer to call update_motor_speed periodically.
        self.timer = Timer(-1)
        self.timer.init(period=timer_period, mode=Timer.PERIODIC, callback=self.update_motor_speed)
    
    def _encoder_isr(self, pin):
        """
        Encoder interrupt handler.
        Checks the value of encoder_pin_b to determine rotation direction.
        """
        if self.encoder_pin_b.value() == 1:
            self.encoder_count += 1  # Forward rotation
        else:
            self.encoder_count -= 1  # Reverse rotation

    def set_motor_speed(self, speed):
        """
        Sets the motor speed and direction by adjusting the PWM duty cycle.
        """
        speed = max(min(speed, 65535), -65535)  # Limit the PWM duty cycle
        
        if speed == 0:
            self.motor_pwm1.duty_u16(0)
            self.motor_pwm2.duty_u16(0)
        elif speed > 0:
            self.motor_pwm1.duty_u16(0)
            self.motor_pwm2.duty_u16(int(speed))
        else:
            self.motor_pwm1.duty_u16(int(-speed))
            self.motor_pwm2.duty_u16(0)
    
    def update_motor_speed(self, t):
        """
        Called periodically by the Timer.
        Computes the actual RPM, calculates PID error, and adjusts the motor PWM.
        """
        current_time = time.ticks_ms()
        dt = time.ticks_diff(current_time, self.last_time) / 1000.0  # Convert to seconds
        
        # Calculate RPM
        if dt > 0:
            self.rpm = (self.encoder_count * 60 / self.ticks_per_rev) / dt
        else:
            self.rpm = 0
        
        # Reset encoder count and update the last time measurement.
        self.encoder_count = 0
        self.last_time = current_time
        
        # Compute error
        error = self.target_rpm - self.rpm

        # Integral term with decay when target RPM is zero
        if self.target_rpm == 0:
            self.integral *= 0.9  # Decay integral when not in use
        else:
            self.integral += error * dt  # Normal integral
            
        derivative = (error - self.last_error) / dt if dt > 0 else 0

        # Compute PID output
        output = (self.Kp * error) + (self.Ki * self.integral) + (self.Kd * derivative)
        
        self.last_error = error  
        
        # Debug output
#         print("Target RPM: {:0.2f}, Measured RPM: {:.2f}, Error: {:.2f}, Integral: {:.2f}, Output: {:.2f}"
#               .format(self.target_rpm, self.rpm, error, self.integral, output))
        
        # Set motor speed
        self.set_motor_speed(output)
    
    def get_rpm(self):
        """
        Returns the current measured RPM.
        """
        return self.rpm


# Initialize Motors
motor1 = Motor(pwm_pin_forward=0, pwm_pin_reverse=1, encoder_pin_a=11, encoder_pin_b=10)
motor2 = Motor(pwm_pin_forward=2, pwm_pin_reverse=3, encoder_pin_a=13, encoder_pin_b=12)
motor3 = Motor(pwm_pin_forward=6, pwm_pin_reverse=7, encoder_pin_a=15, encoder_pin_b=14)

# Movement Functions
def reverse():
    motor1.target_rpm = -50 
    motor3.target_rpm = 50

def forward():
    motor1.target_rpm = 50 
    motor3.target_rpm = -50

def rotateR():
    motor1.target_rpm = 50
    motor2.target_rpm = 50
    motor3.target_rpm = 50

def rotateL():
    motor1.target_rpm = -50
    motor2.target_rpm = -50
    motor3.target_rpm = -50

def stop():
    motor1.target_rpm = 0
    motor2.target_rpm = 0
    motor3.target_rpm = 0

# Directional Movements
def forwardR():
    motor2.target_rpm = -50 
    motor3.target_rpm = 50

def reverseR():
    motor2.target_rpm = 50 
    motor3.target_rpm = -50

def forwardL():
    motor2.target_rpm = -50 
    motor1.target_rpm = 50

def reverseL():
    motor2.target_rpm = 50 
    motor1.target_rpm = -50


# Main Loop
while True:
    motor1.target_rpm = 50
    motor3.target_rpm = -50
    motor2.target_rpm = 0
    print("Motor1 RPM:", motor1.get_rpm(), "Motor2 RPM:", motor2.get_rpm(), "Motor3 RPM:", motor3.get_rpm())
    time.sleep(0.1)

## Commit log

2024-11-06 Working index layout, add some functionality
    icons and text change depending on charge percent and if there is any issue.
2024-11-25 Fixed selected tab icons disappearing on mobile devices in lightmode
2025-01-08 Made cahnges to machine vision, Omni wheel control
2025-01-08 added code for scissor lift and assembly
    [final scissor lift assembly v1.f3z]
2025-01-09 pricing spreadsheets
    [PricingSpreadsheet.xlsx]
2025-01-13 Created Basic Demo Program
    This program zeroes the scissor lift against the value read from the linear encoder, and then rises the lift up. The robot then moves forward for one second, and the scissor lift then lowers again. Then, the robot reverses for one second. It does this on a loop.
    [LiftAndMove.ino]
2025-01-13 The most up to date Full Assembly
    crunch time
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2025-01-14 Added Detail Around PCB Design
2025-01-22 Update local furniture json file working
    Can add new furniture which would be store in the local device into json file, not to the json file in source which I was trying before.
2025-01-25 Set current visual location on grid (Add Layout)
2025-01-27 Update hub_communication to avoid using hostname for mobile devices (errors out)
2025-01-31 verified PID with 2 Motors
2025-01-31 Add & delete furniture functions, manage buttons
2025-02-07 Updated PID code for new motors, helped by dan :)
2025-02-17 PID tuning, adapting Aruco Marker detection for ROS
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2025-02-21 output data of box moved with extra bracket
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2025-03-02 Started adding Library Filter buttons
2025-03-02 Make current and desired furniture update correctly
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2025-03-09 Minor visual changes to addFurniture. Printing not possible
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2025-04-06 QR code now saves to camera roll.
    Using the expo media library package, the system requests user permission and saves to a camera roll. This is a draft fix, requiring better usage of permissions and file paths. Maybe adding the name to the top of the image too for ease.
2025-04-07 Added the running page wireframe.
    This is the page that will be shown when users are running the system. Currently its a wireframe showing the positions of elements and minimal work has been done towards functionality. The robots lis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
2025-04-08 Setup emergency stop in backend
    Setup and tested the emergency stop button within the running page. It now sends a "stop" event to each robot. Needs to be tested on actual robot and multiple simulated. Added documentation for simul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
2025-04-14 Added a login button and conditional rendering.
    If the user is not logged in, the index displays a login button. This is so if they close the login popup, it can be called again. Could be changed so that it is only callable. Added this to addLayout too, so when the user presses ready to go, it only shows the page if the websocket is connected. Need to fix the login button styling.
2025-04-14 Setup local device sqlite db authentication.
    The login modal now creates and manages db interactions. It now creates a unique sqlite db file and table per device (bad in industry, ok for module), and allows the user to add accounts / login. Cur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
2025-04-15 Moved db management into provider and optimised.
    Since access to the db will be required in the settings page (deleting accounts, changing names etc), the db setup has been moved to authorisationProvider and provided as a hook. Now the system can c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
2025-04-16 correct data for odom
    [PID-Control.ino]
2025-04-19 Setting up Layout saving in JSON file.
    I have been developing a way to save the layout information into a json file. Currently it creates the file, saves the data, but there are minor issues involving duplication, and saving current_layout and new_layout. For some reason they overwrite one another, need to fix. Added a clear layouts button while developing.
2025-04-19 Library now loads layouts and layouts have titles.
    The library now accesses the layouts json and displays the users layouts. Fixed an overwriting issue in addLayout by grabbing the other saved layouts and ensuring they remain when writing the new data. Each layout now requires a title, helping to identify it and display in the library. Still need to fix the duplication error and the library page needs to reload more dynamically, currently only reloading on user changes.
2025-04-20 Layouts are now pressable and load layout page.
    Layouts send across their title using link and params, loading the addLayout page. The addlayout page now listens to when users press the saved layout and updates the page title. Currently it only updates the title but it does get the ID's of each box, so can get their information. Need to figure out how to set the boxes correctly.
2025-04-20 adding odometry PID and manual control to main
2025-04-20 added rpm calculation for wheels based on twist
2025-04-21 Moving arduino to folder
2025-04-21 Fixed layout issues regarding keys and names.
    Fixed the issue where layouts could be saved under the same name. In turn this (as well as setting the smallLayout keys) fixed the child props issue in the library by ensuring they had keys and they were unique. Tidied up addLayout a bit. Updated the readme with an alternative way of opening the app on Expo Go.
2025-04-21 Added some more account settings.
    Added delete account, delete layouts, delete ALL layouts, and delete ALL accounts. While not essential to the project these show good db and json management, useful for testing and ensuring the devic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
2025-04-22 Added manual refreshing in the library.
    Users can now drag down from the top of the screen to manually refresh it. Only applied to the library currently.
2025-04-22 fixed orientation issues and added exit handling
    [main.ino]
2025-04-23 Fixed duplication error.
    Adding all boxes and placed boxes was the error that caused the data to duplicate when saving. Fixed this by removing one of the 2 options and testing each way round. The solution was placed boxes for current and boxes for new. Need to test with added furniture.
2025-04-23 Bug fixing attempt for box locations.
    Attempting to fix the location of boxes when users select a saved layout. Currently this gets the positions close to their desired position but is offset due to the furniture dimensions. Might be an equation problem.
2025-04-25 Added password changing and minor visual edits.
    Users can now change their passwords in the account settings page. Visual edits have been added to help differentiate buttons and functions. Attempting to make a login inputs component to make it easier to add to settings but not working very well.
2025-04-28 Added the grid to the system running page.
    Copied across the grid from the addLayout page, keeping the key functionality and removing the rest. It now shows the grid, the current title, and displays the box coordinates when selected. Need to fix the design and coordinates. Added extra changes to a few other pages, tidying functions and improving the return view.
2025-04-29 Fixed issues with QR code and boxes on the grid.
    The QR code displays when the websocket has qrcode data and this data would not clear, resulting in the qr code always being visible, even after the form resets. Now the qr code local variable (QRData) only updates once the save furniture button has been pressed, getting the new QR code. After fixing the issue with loading box coordinates from the library, it meant that adding a layout normally would result in no boxes appearing at the start. This was due to an incorrect condition only checking if the useEffect had been called. Now it checks that as well as if the selectedLayout is not empty, since it would return {}, counting as not empty. It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
2025-04-30 Fixed saving layout issues and added overwriting.
    The biggest issue preventing the live simulation working was that the layouts would not overwrite just simply append with a new name. Before running the simulation, the layouts need to be saved to update for any changes. With this, the user would have to change the layout name, making saving redundant. Now the system checks if its a new or loaded layout and overwrites it accordingly. For the simulation, the grey boxes represent the target destinations instead of the "current layout", as an easy-to-understand visual for the user.
2025-05-01 Added layout favouriting functionality.
    Users can now save layouts by toggling the star icon on each small layout. In doing so, it overwrites the "favourited" json value for the layout, providing filtering functionality. Would be useful fo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
2025-05-01 Major visual changes update.
    Improved colour scheme, settings organisation, and font management. Need to test on actual device rather than emulation and need to decide what's happening with add page and room manager. Most of the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
2025-05-06 Manage furniture and layouts almost done.
    Manage furniture now shows the current list of furnitures and a small image to display their appearance. The images do sometimes overflow, which needs to be fixed using css and scaling, maybe adding a scale at the bottom too. Both small furniture and layout have been optimised by limiting the useeffect, improving performance especially with favouriting. Started working on saving the roomScan image and the qr image.
2025-05-11 Added json clearing and filter button icons.
    Originally the users would be able to clear all layouts in the account settings, but since each room now has its own jsons with each user having layouts, the system has pivoted towards more dynamic c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
2025-05-11 Added colours to the filter buttons.
2025-05-11 Visual updates to the roomDetails page.
    Changed the UI of the roomDetails page to be more user friendly, including improved colours, icons, and button placement.
2025-05-13 Fixing smallRooms, issue with timings.
    SmallRooms currently work, they load the correct data and can be deleted. However, there is an issue with updating the data (required for toggling favourites and updating info). While the smallRooms will not need to update information from within, the ability to do so could prove useful. Need to fix room provider functionality first.
2025-05-13 adding lfs for cad files
2025-05-13 normalised maths for twists and odometry
2025-05-13 adding scissor lift fusion files
    [Scissor Assembly v15.f3z, final scissor lift assembly v1.f3z, new base plate v4.f3z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]
2025-05-13 Made separate scanning page and tested saving.
    A separate scanning page has been added since controller is now part of the tabs list, changing the UI of the page and causing issues with the local parameter search. Tested png saving by having the scanning page's save button save a random png into the jsonData. Should be consistent when fully testing. New issue found with new users accessing rooms and not being added into the JSON, need to fix.
2025-05-14 roomScan sends across, button Icon changes.
2025-05-14 Add set mode and load map, remove some spamming print messages
2025-05-14 Visual updates in the app and removing WIP.
    Changed button styles, removed parts that were not finished / working. Need to do final tests and run with the robot.
2025-05-14 Added videos file.
    Currently contains the scissor lift animation and two app tutorial videos.
2025-05-14 added led bumper and new updated baseplate
    [LED bumper v7.f3d, new base plate v4.f3z, new base plate v7.f3z]
2025-05-14 Converted ws to wss on home network.
    Currently the system is running on wss, but this has not been tested on the respace network, need to test.
2025-05-15 updating CAD
    [Scissor Assembly v15.f3z, Scissor Assembly v20.f3z, new base plate v11.f3z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]
2025-05-15 me and dan made new top plate
    [Scissor Assembly v20.f3z, Scissor Assembly v22.f3z, new top of lift v2.f3z]
2025-05-16 changed orientation of robot and fixed a bunch of other things
    [main.ino]
2025-05-16 uploading cad 3d models
    [Alternate Motor Mount v1.f3d, Bottom Plate v9.f3d, Lower Post v7.f3d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]
2025-05-16 some forklift prototyping CAD
    [base mk2 v2.stl, base v4.stl, bottom of face cam v1.stl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]
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2025-05-16 adding assembly
    [Full Assembly v51.f3z]
